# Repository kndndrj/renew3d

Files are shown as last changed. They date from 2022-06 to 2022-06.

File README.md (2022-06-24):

# Renew3D
A simple, cheap and (hopefully) reliable 3D printer.

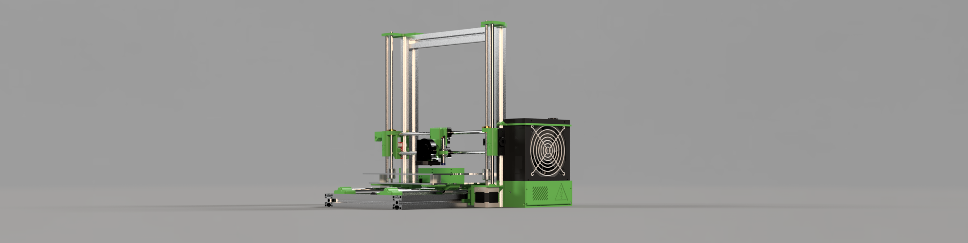
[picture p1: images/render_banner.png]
render


[More images here.](images/)

###### What kind of name is this?
I built my first 3D printer a couple of years ago, but there was no assembly,
only parts from thingiverse, etc. Then I had an idea to make a new printer with
extra features, but the project became *waaay* to complicated (check it
[here](https://github.com/kndndrj/complicator-3000)). So this printer here, is
a "renewed" version of those two (quite bad, I know).

## Getting Started
The files for this printer are available in `.f3d`, `.step` and `.stl` formats.
If you want to assemble the printer, I suggest that you check
[`assembly.f3z`](cad/assembly.f3z) (alternatively `assembly.step`) first, and
check what materials to buy and what parts to print. Then look into the
[`printed_parts`](cad/printed_parts) directory and browse files in different
formats. If you have a sensor, board, hotend, etc. check the `extras`
directory.

## Firmware Uploading (Linux)
You can use any firmware you like, here is just my example config using Marlin
2.0.x for Ramps board with mega 2560.

1. Download Marlin Firmware [here](https://github.com/MarlinFirmware/Marlin).
2. Install platformio (example on Arch Linux):
	```sh
	$ paru -S platformio
	```
3. Go to the downloaded firmware directory and replace `Marlin/Configuration.h`
   and `Marlin/Configuration_adv.h` with files from [`firmware`](firmware) in
   this repository.
4. Plug in the printer and run:
	```sh
	$ platformio run --target upload -e mega2560
	```

#### Note on cheap Chinese boards
Try these steps (stop when you get it to work):
- Install `i2c-ch341-dkms` from AUR.
- Disable udev rules:
	```
	/usr/lib/udev/rules.d/90-brltty-device.rules
	/usr/lib/udev/rules.d/90-brltty-uinput.rules
	```
- Specify `upload_port = /dev/ttyUSB0` in `ini/avr.ini`

## Development

#### Specific Components
If you are creating a new specific part (like SKR 1.3), put it in the `extras`
directory. If it's made of multiple bodies, export the whole file as `.f3d` and
`.step`. Then export separate bodies (only printable parts) as `.stl`.

#### Main Assembly
For main assembly, use only the `assembly.f3z` when developing. then export the
modified printable parts in all formats and put them in `main_assembly`
directory.

## Credits

#### Standard Parts 3D Models:

**NOTE:** I'm not the owner of any of the following "standard" parts.

- [atx_power_supply](https://grabcad.com/library/atx-power-supply-1)
- [cooling_fan_4010](https://grabcad.com/library/40mm-dc-fan-1)
- [cooling_fan_radial_5015](https://grabcad.com/library/radial-cooling-5015-fan-50mm-dc12v-1/details?folder_id=2074285)
- [e3d_v6_hotend](https://grabcad.com/library/e3d-v6-hotend-1-75mm-bowden-1)
- [endstop_switch](https://grabcad.com/library/mechanical-endstop-module-1)
- [flex_coupler_5x8]()https://grabcad.com/library/flex-coupler-5mm-8mm-1
- [GT2_20T_motor](https://grabcad.com/library/timing-pulley-gt2-20-teeth-5mm-bore-2/details?folder_id=2369004)
- [GT2_20T_idler](https://grabcad.com/library/tension-pulley-gt2-20t-b5-1)
- [induction_sensor_m12](https://grabcad.com/library/lj12a3-4-z_bx-inductive-sensor-m12-1)
- [lead_screw_nut_t8](https://grabcad.com/library/tr8x8-4-8mm-4-start-lead-screw-nut-1)
- [lead_screw_t8_340](https://grabcad.com/library/tr8x8-4-8mm-4-start-lead-screw-1)
- [linear_bearing_LM8UU](https://grabcad.com/library/lm8uu-11)
- [nema_17_motor](https://grabcad.com/library/step-motor-nema-17-1)
- [ramps_14_arduino_mega_2560](https://grabcad.com/library/arduino-mega-ramps-1-4-1)
- [ramps_lcd_adapter](https://grabcad.com/library/smart-adapter-conector-lcd-ramps-1-4-1)
- [SSR_40_DA](https://grabcad.com/library/ssr-40-da-1)

#### Printed Parts:

- [part_cooling_fan_duct](https://www.thingiverse.com/thing:3063554) - changed only text
- [x_idler & x_motor_holder](https://www.thingiverse.com/thing:1103976) - fork
- [x_carriage & hotend_holder](https://www.thingiverse.com/thing:2023947) - fork
- [y_endstop_holder](https://www.thingiverse.com/thing:919432/files) - inspiration

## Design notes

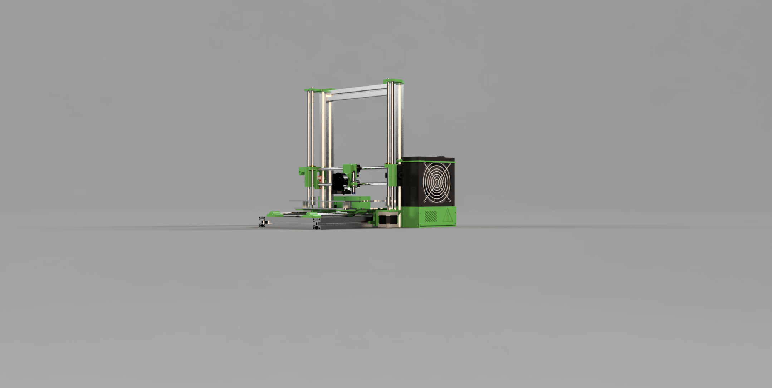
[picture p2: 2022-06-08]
images/render.png

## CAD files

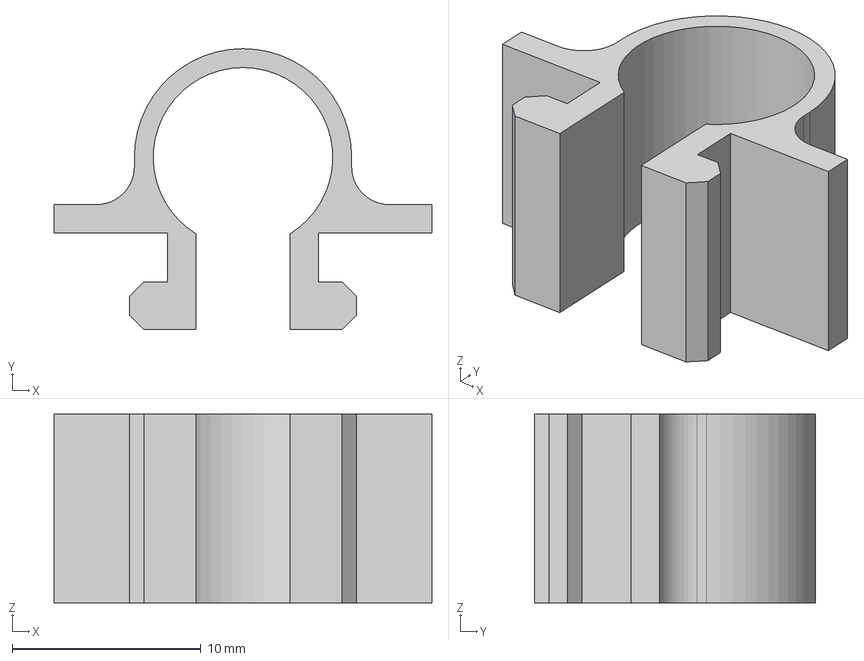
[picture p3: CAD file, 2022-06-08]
cad/printed_parts/extras/step/cable_clip.step
20.0 x 14.8 x 10.0 mm

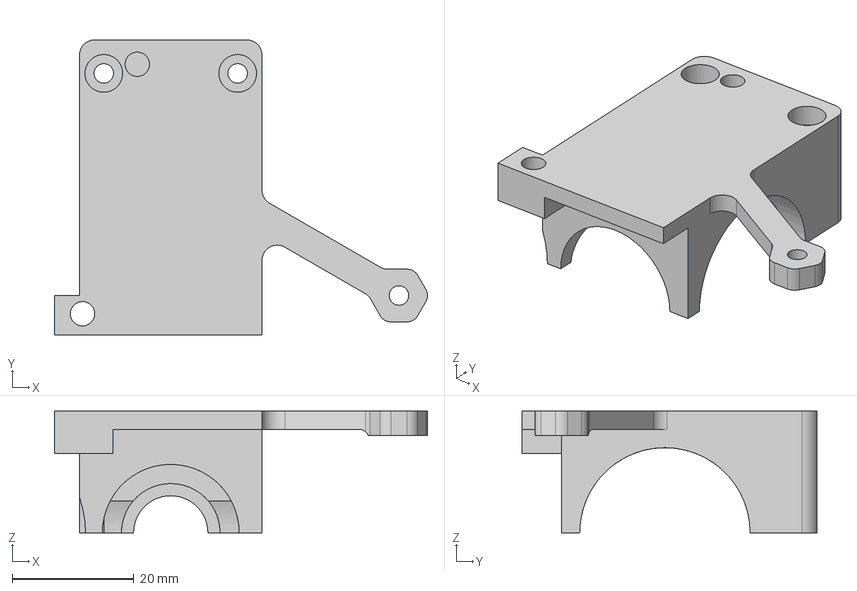
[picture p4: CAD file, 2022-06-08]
cad/printed_parts/main_assembly/step/hotend_holder_cover.step
61.3 x 48.5 x 20.0 mm

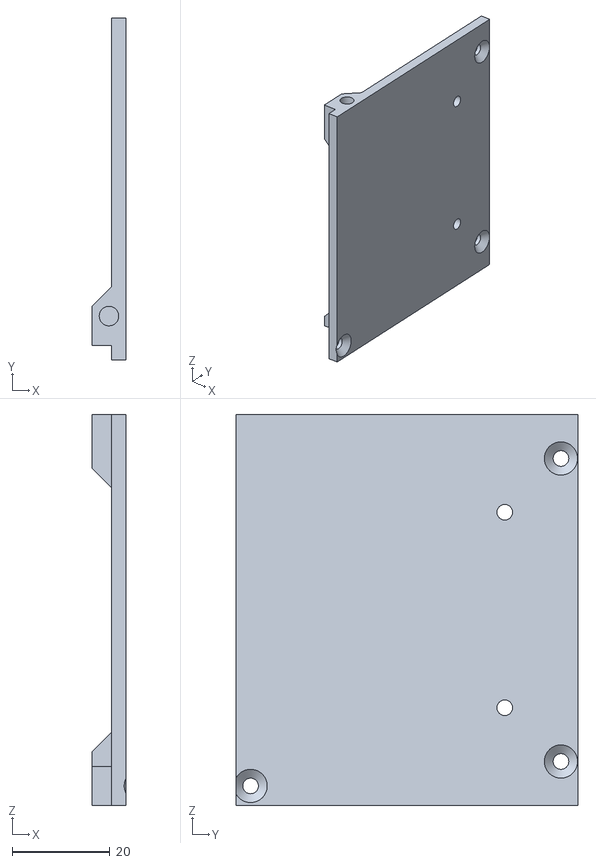
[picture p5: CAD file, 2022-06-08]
cad/printed_parts/main_assembly/stl/ramps_enclosure_right.stl
7.00 x 70.0 x 80.0

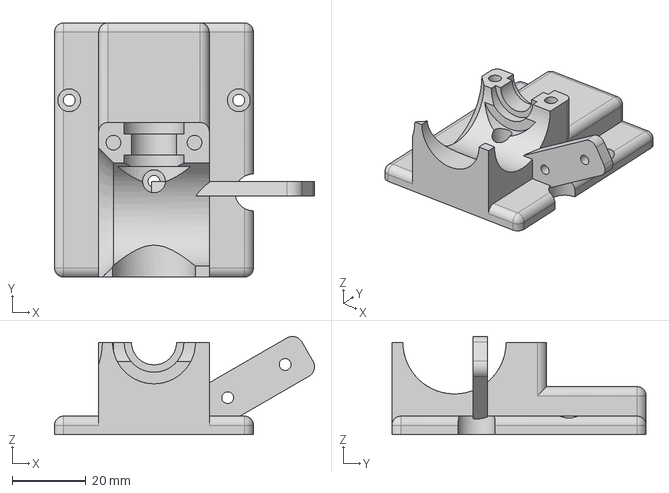
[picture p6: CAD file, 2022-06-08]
cad/printed_parts/extras/step/hotend_holder_back_bl_touch.step
70.6 x 69.0 x 26.6 mm

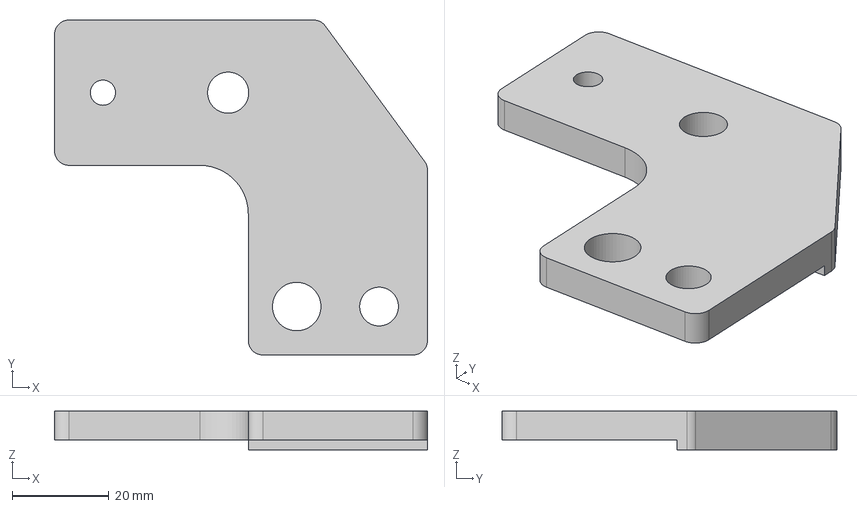
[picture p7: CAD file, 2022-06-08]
cad/printed_parts/main_assembly/step/z_guide_holder_right.step
77.0 x 69.2 x 8.00 mm

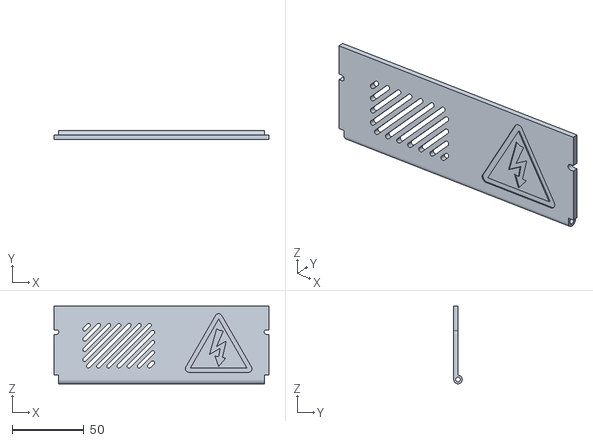
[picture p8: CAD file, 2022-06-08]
cad/printed_parts/main_assembly/stl/ssr_enclosure_front.stl
149.5 x 6.00 x 54.0

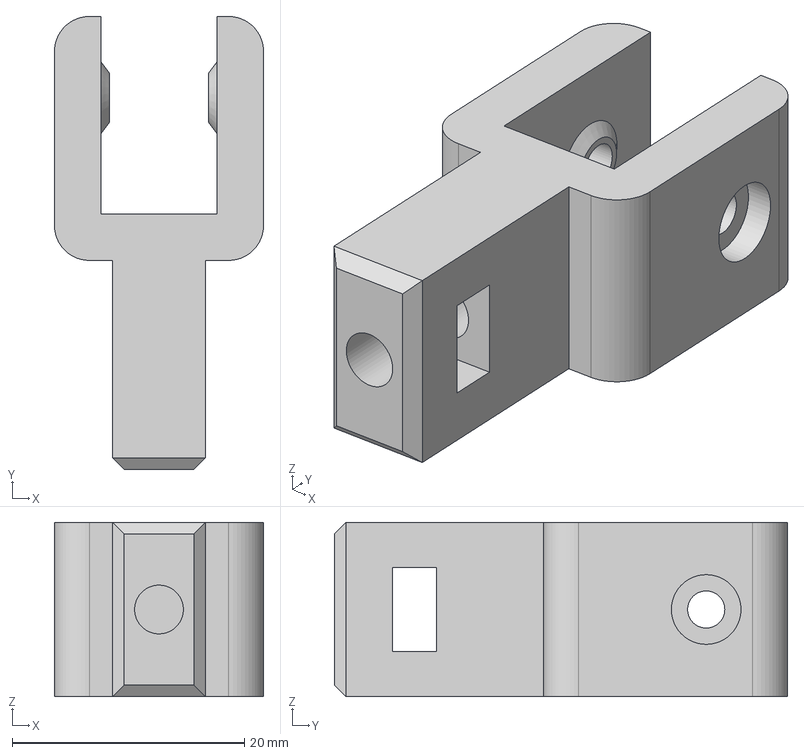
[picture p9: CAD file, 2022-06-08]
cad/printed_parts/main_assembly/step/tension_arm.step
18.0 x 39.0 x 15.0 mm

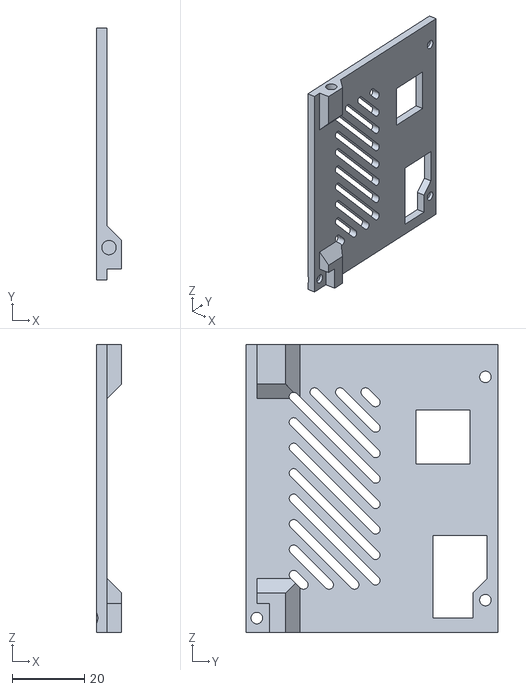
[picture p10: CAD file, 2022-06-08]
cad/printed_parts/main_assembly/stl/ramps_enclosure_left.stl
7.00 x 70.0 x 80.0

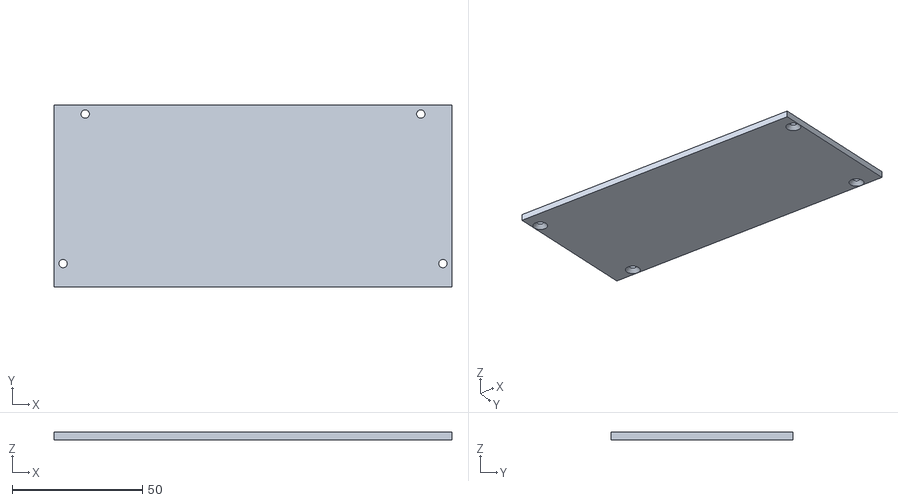
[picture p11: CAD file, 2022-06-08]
cad/printed_parts/main_assembly/stl/ramps_enclosure_bottom.stl
153.0 x 70.0 x 3.00

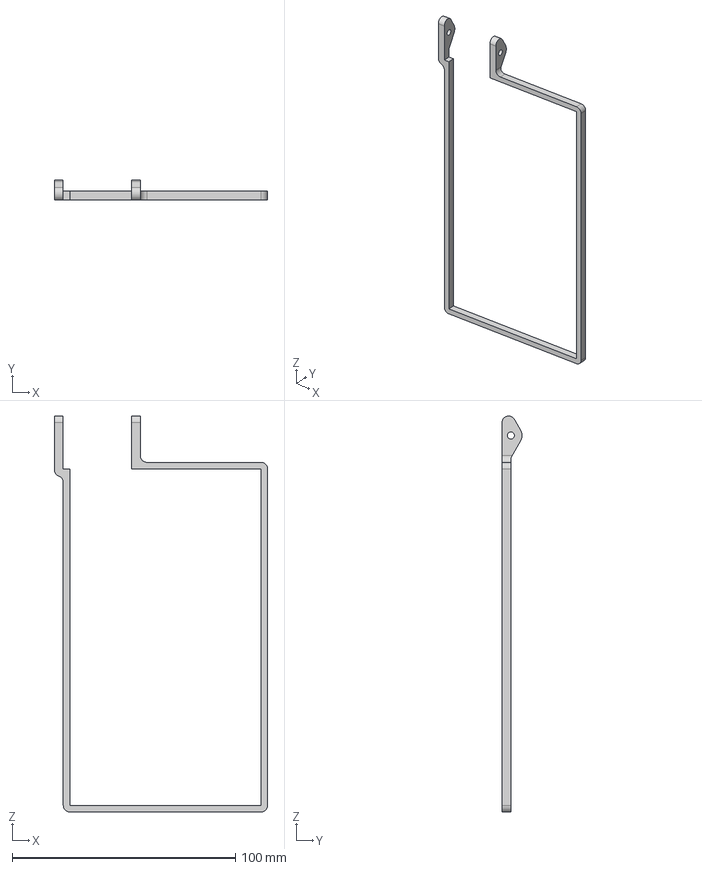
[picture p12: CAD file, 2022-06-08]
cad/printed_parts/main_assembly/step/psu_support.step
95.5 x 8.99 x 177.2 mm

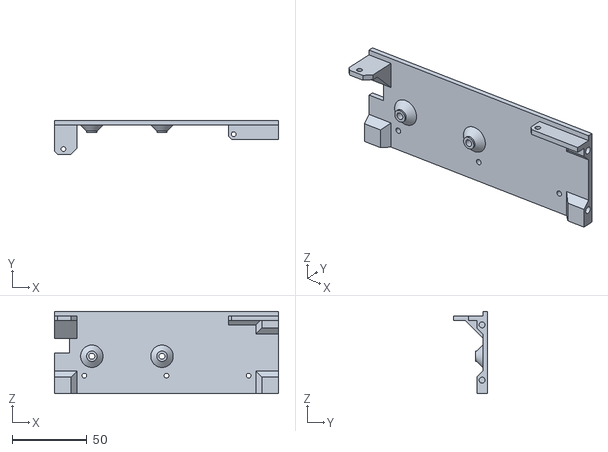
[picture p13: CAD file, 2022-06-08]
cad/printed_parts/main_assembly/stl/ssr_enclosure_back.stl
150.0 x 22.5 x 55.0

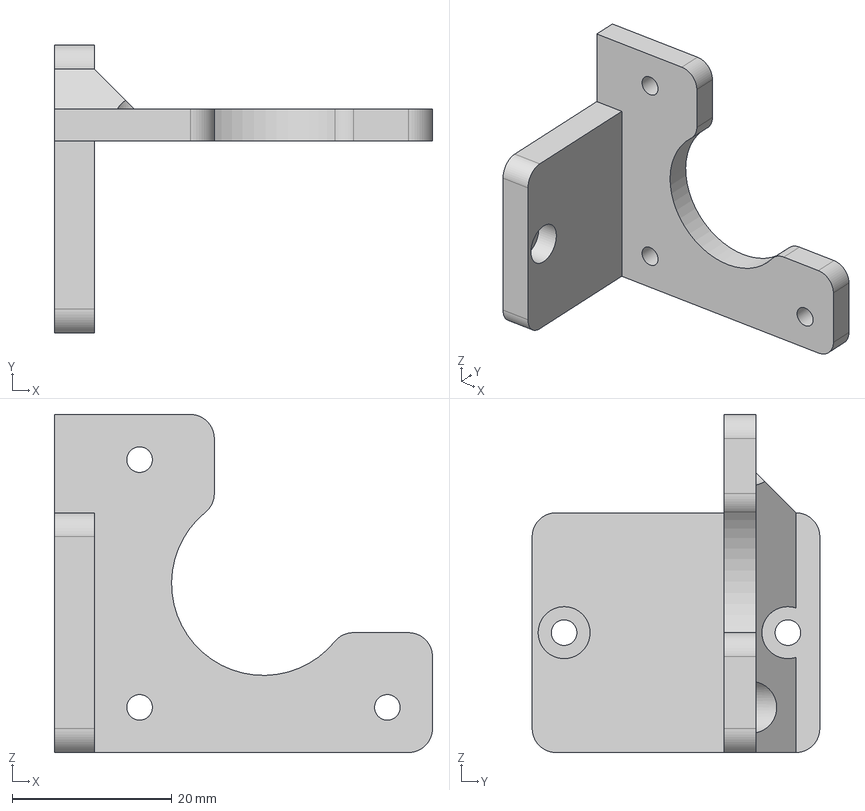
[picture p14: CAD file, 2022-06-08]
cad/printed_parts/main_assembly/step/y_motor_holder.step
47.3 x 36.0 x 42.3 mm

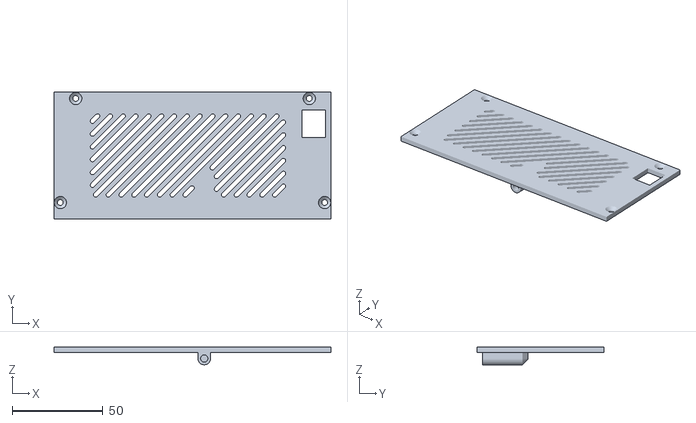
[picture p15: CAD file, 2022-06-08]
cad/printed_parts/main_assembly/stl/ramps_enclosure_top.stl
153.0 x 70.0 x 9.74

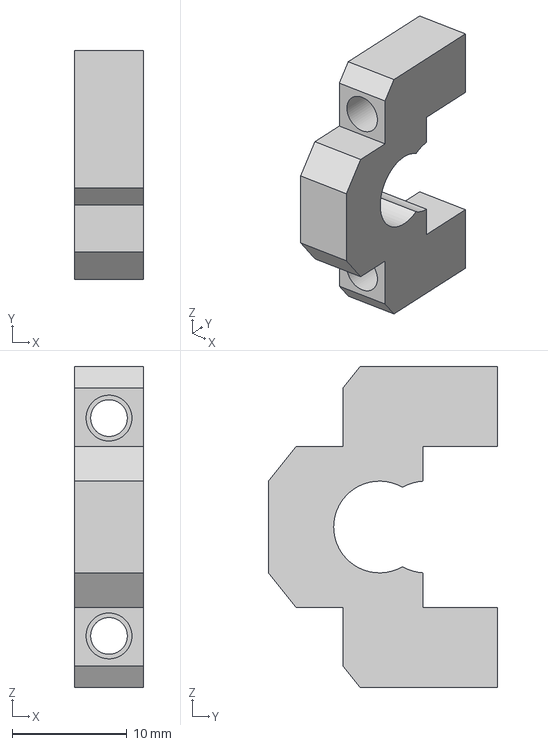
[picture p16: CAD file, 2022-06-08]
cad/printed_parts/main_assembly/step/y_endstop_holder.step
6.00 x 20.0 x 28.0 mm

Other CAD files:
cad/printed_parts/main_assembly/stl/ssr_enclosure_left.stl
cad/printed_parts/main_assembly/step/x_tensioner.step
cad/printed_parts/main_assembly/stl/ssr_enclosure_bottom.stl
cad/printed_parts/main_assembly/step/x_idler.step
cad/printed_parts/extras/f3d/cable_clip.f3d
cad/printed_parts/extras/f3d/hotend_holder_bl_touch.f3d
cad/printed_parts/extras/stl/cable_clip.stl
cad/printed_parts/extras/stl/hotend_holder_back_bl_touch.stl
cad/printed_parts/main_assembly/f3d/hotend_holder_induction_probe_12.f3d
cad/printed_parts/main_assembly/f3d/part_cooling_fan_duct.f3d
cad/printed_parts/main_assembly/f3d/psu_support.f3d
cad/printed_parts/main_assembly/f3d/screw_wheel_20_m4.f3d
cad/printed_parts/main_assembly/f3d/screw_wheel_27_m4.f3d
cad/printed_parts/main_assembly/f3d/screw_wheel_60_m3.f3d
cad/printed_parts/main_assembly/f3d/tension_arm.f3d
cad/printed_parts/main_assembly/f3d/x_carriage.f3d
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

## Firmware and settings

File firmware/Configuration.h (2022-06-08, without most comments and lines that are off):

#pragma once
#define CONFIGURATION_H_VERSION 02000903
#define STRING_CONFIG_H_AUTHOR "(Andrej Kenda, Renew3D config)" // Who made the changes.
#define SHOW_BOOTSCREEN
  #define MOTHERBOARD BOARD_RAMPS_14_EFB
#define SERIAL_PORT 0
#define BAUDRATE 250000
#define CUSTOM_MACHINE_NAME "Renew3D"
#if LINEAR_AXES >= 4
  #define AXIS4_NAME 'A' // :['A', 'B', 'C', 'U', 'V', 'W']
#endif
#if LINEAR_AXES >= 5
  #define AXIS5_NAME 'B' // :['A', 'B', 'C', 'U', 'V', 'W']
#endif
#if LINEAR_AXES >= 6
  #define AXIS6_NAME 'C' // :['A', 'B', 'C', 'U', 'V', 'W']
#endif
#define EXTRUDERS 1
#define DEFAULT_NOMINAL_FILAMENT_DIA 1.75
#define TEMP_SENSOR_0 1
#define TEMP_SENSOR_1 0
#define TEMP_SENSOR_2 0
#define TEMP_SENSOR_3 0
#define TEMP_SENSOR_4 0
#define TEMP_SENSOR_5 0
#define TEMP_SENSOR_6 0
#define TEMP_SENSOR_7 0
#define TEMP_SENSOR_BED 75
#define TEMP_SENSOR_PROBE 0
#define TEMP_SENSOR_CHAMBER 0
#define TEMP_SENSOR_COOLER 0
#define TEMP_SENSOR_BOARD 0
#define TEMP_SENSOR_REDUNDANT 0
#define DUMMY_THERMISTOR_998_VALUE  25
#define DUMMY_THERMISTOR_999_VALUE 100
#define TEMP_RESIDENCY_TIME         10  // (seconds) Time to wait for hotend to "settle" in M109
#define TEMP_WINDOW                  1  // (°C) Temperature proximity for the "temperature reached" timer
#define TEMP_HYSTERESIS              3  // (°C) Temperature proximity considered "close enough" to the target
#define TEMP_BED_RESIDENCY_TIME     10  // (seconds) Time to wait for bed to "settle" in M190
#define TEMP_BED_WINDOW              1  // (°C) Temperature proximity for the "temperature reached" timer
#define TEMP_BED_HYSTERESIS          3  // (°C) Temperature proximity considered "close enough" to the target
#define TEMP_CHAMBER_RESIDENCY_TIME 10  // (seconds) Time to wait for chamber to "settle" in M191
#define TEMP_CHAMBER_WINDOW          1  // (°C) Temperature proximity for the "temperature reached" timer
#define TEMP_CHAMBER_HYSTERESIS      3  // (°C) Temperature proximity considered "close enough" to the target
#if TEMP_SENSOR_REDUNDANT
  #define TEMP_SENSOR_REDUNDANT_SOURCE    E1  // The sensor that will provide the redundant reading.
  #define TEMP_SENSOR_REDUNDANT_TARGET    E0  // The sensor that we are providing a redundant reading for.
  #define TEMP_SENSOR_REDUNDANT_MAX_DIFF  10  // (°C) Temperature difference that will trigger a print abort.
#endif
#define HEATER_0_MINTEMP   10
#define HEATER_1_MINTEMP   5
#define HEATER_2_MINTEMP   5
#define HEATER_3_MINTEMP   5
#define HEATER_4_MINTEMP   5
#define HEATER_5_MINTEMP   5
#define HEATER_6_MINTEMP   5
#define HEATER_7_MINTEMP   5
#define BED_MINTEMP        10
#define CHAMBER_MINTEMP    5
#define HEATER_0_MAXTEMP 275
#define HEATER_1_MAXTEMP 275
#define HEATER_2_MAXTEMP 275
#define HEATER_3_MAXTEMP 275
#define HEATER_4_MAXTEMP 275
#define HEATER_5_MAXTEMP 275
#define HEATER_6_MAXTEMP 275
#define HEATER_7_MAXTEMP 275
#define BED_MAXTEMP      90
#define CHAMBER_MAXTEMP  60
#define HOTEND_OVERSHOOT 15   // (°C) Forbid temperatures over MAXTEMP - OVERSHOOT
#define BED_OVERSHOOT    10   // (°C) Forbid temperatures over MAXTEMP - OVERSHOOT
#define COOLER_OVERSHOOT  2   // (°C) Forbid temperatures closer than OVERSHOOT
#define PIDTEMP
#define BANG_MAX 255     // Limits current to nozzle while in bang-bang mode; 255=full current
#define PID_MAX BANG_MAX // Limits current to nozzle while PID is active (see PID_FUNCTIONAL_RANGE below); 255=full current
#define PID_K1 0.95      // Smoothing factor within any PID loop
    #define DEFAULT_Kp 12.54
    #define DEFAULT_Ki 0.59
    #define DEFAULT_Kd 66.76
#define PIDTEMPBED
#define MAX_BED_POWER 255 // limits duty cycle to bed; 255=full current
  #define DEFAULT_bedKp 29.51
  #define DEFAULT_bedKi 5.00
  #define DEFAULT_bedKd 116.02
#define MAX_CHAMBER_POWER 255 // limits duty cycle to chamber heater; 255=full current
  #define PID_FUNCTIONAL_RANGE 10 // If the temperature difference between the target temperature and the actual temperature
#define PREVENT_COLD_EXTRUSION
#define EXTRUDE_MINTEMP 170
#define PREVENT_LENGTHY_EXTRUDE
#define EXTRUDE_MAXLENGTH 200
#define THERMAL_PROTECTION_HOTENDS // Enable thermal protection for all extruders
#define THERMAL_PROTECTION_BED     // Enable thermal protection for the heated bed
#define THERMAL_PROTECTION_CHAMBER // Enable thermal protection for the heated chamber
#define THERMAL_PROTECTION_COOLER  // Enable thermal protection for the laser cooling
#define USE_XMIN_PLUG
#define USE_YMIN_PLUG
#define USE_ZMIN_PLUG
#define ENDSTOPPULLUPS
#define X_MIN_ENDSTOP_INVERTING true  // Set to true to invert the logic of the endstop.
#define Y_MIN_ENDSTOP_INVERTING true  // Set to true to invert the logic of the endstop.
#define Z_MIN_ENDSTOP_INVERTING false // Set to true to invert the logic of the endstop.
#define I_MIN_ENDSTOP_INVERTING false // Set to true to invert the logic of the endstop.
#define J_MIN_ENDSTOP_INVERTING false // Set to true to invert the logic of the endstop.
#define K_MIN_ENDSTOP_INVERTING false // Set to true to invert the logic of the endstop.
#define X_MAX_ENDSTOP_INVERTING false // Set to true to invert the logic of the endstop.
#define Y_MAX_ENDSTOP_INVERTING false // Set to true to invert the logic of the endstop.
#define Z_MAX_ENDSTOP_INVERTING false // Set to true to invert the logic of the endstop.
#define I_MAX_ENDSTOP_INVERTING false // Set to true to invert the logic of the endstop.
#define J_MAX_ENDSTOP_INVERTING false // Set to true to invert the logic of the endstop.
#define K_MAX_ENDSTOP_INVERTING false // Set to true to invert the logic of the endstop.
#define Z_MIN_PROBE_ENDSTOP_INVERTING false // Set to true to invert the logic of the probe.
#define X_DRIVER_TYPE  DRV8825
#define Y_DRIVER_TYPE  DRV8825
#define Z_DRIVER_TYPE  DRV8825
#define E0_DRIVER_TYPE DRV8825
#define DEFAULT_AXIS_STEPS_PER_UNIT   { 160, 160, 800, 192 }
#define DEFAULT_MAX_FEEDRATE          { 100, 100, 5, 25 }
#define DEFAULT_MAX_ACCELERATION      { 900, 900, 100, 5000 }
#define DEFAULT_ACCELERATION          1000    // X, Y, Z and E acceleration for printing moves
#define DEFAULT_RETRACT_ACCELERATION  1000    // E acceleration for retracts
#define DEFAULT_TRAVEL_ACCELERATION   1000    // X, Y, Z acceleration for travel (non printing) moves
#define CLASSIC_JERK
  #define DEFAULT_XJERK 10.0
  #define DEFAULT_YJERK 10.0
  #define DEFAULT_ZJERK  0.4
#define DEFAULT_EJERK    5.0  // May be used by Linear Advance
#define Z_MIN_PROBE_USES_Z_MIN_ENDSTOP_PIN
#define USE_PROBE_FOR_Z_HOMING
#define BLTOUCH
#define NOZZLE_TO_PROBE_OFFSET { 23, 3, -1.5 }
#define PROBING_MARGIN 10
#define XY_PROBE_FEEDRATE (133*60)
#define Z_PROBE_FEEDRATE_FAST (4*60)
#define Z_PROBE_FEEDRATE_SLOW (Z_PROBE_FEEDRATE_FAST / 2)
#define Z_CLEARANCE_DEPLOY_PROBE    4 // Z Clearance for Deploy/Stow
#define Z_CLEARANCE_BETWEEN_PROBES  4 // Z Clearance between probe points
#define Z_CLEARANCE_MULTI_PROBE     4 // Z Clearance between multiple probes
#define Z_PROBE_LOW_POINT          -2 // Farthest distance below the trigger-point to go before stopping
#define Z_PROBE_OFFSET_RANGE_MIN -20
#define Z_PROBE_OFFSET_RANGE_MAX 20
#define X_ENABLE_ON 0
#define Y_ENABLE_ON 0
#define Z_ENABLE_ON 0
#define E_ENABLE_ON 0 // For all extruders
#define DISABLE_X false
#define DISABLE_Y false
#define DISABLE_Z false
#define DISABLE_E false             // Disable the extruder when not stepping
#define DISABLE_INACTIVE_EXTRUDER   // Keep only the active extruder enabled
#define INVERT_X_DIR false
#define INVERT_Y_DIR true
#define INVERT_Z_DIR false
#define INVERT_E0_DIR true
#define INVERT_E1_DIR false
#define INVERT_E2_DIR false
#define INVERT_E3_DIR false
#define INVERT_E4_DIR false
#define INVERT_E5_DIR false
#define INVERT_E6_DIR false
#define INVERT_E7_DIR false
#define X_HOME_DIR -1
#define Y_HOME_DIR -1
#define Z_HOME_DIR -1
#define X_BED_SIZE 225
#define Y_BED_SIZE 225
#define X_MIN_POS 0
#define Y_MIN_POS 0
#define Z_MIN_POS 0
#define X_MAX_POS X_BED_SIZE
#define Y_MAX_POS Y_BED_SIZE
#define Z_MAX_POS 200
#define MIN_SOFTWARE_ENDSTOPS
  #define MIN_SOFTWARE_ENDSTOP_X
  #define MIN_SOFTWARE_ENDSTOP_Y
  #define MIN_SOFTWARE_ENDSTOP_Z
  #define MIN_SOFTWARE_ENDSTOP_I
  #define MIN_SOFTWARE_ENDSTOP_J
  #define MIN_SOFTWARE_ENDSTOP_K
#define MAX_SOFTWARE_ENDSTOPS
  #define MAX_SOFTWARE_ENDSTOP_X
  #define MAX_SOFTWARE_ENDSTOP_Y
  #define MAX_SOFTWARE_ENDSTOP_Z
  #define MAX_SOFTWARE_ENDSTOP_I
  #define MAX_SOFTWARE_ENDSTOP_J
  #define MAX_SOFTWARE_ENDSTOP_K
#define AUTO_BED_LEVELING_BILINEAR
  #define ENABLE_LEVELING_FADE_HEIGHT
    #define DEFAULT_LEVELING_FADE_HEIGHT 10.0 // (mm) Default fade height.
  #define SEGMENT_LEVELED_MOVES
  #define LEVELED_SEGMENT_LENGTH 5.0 // (mm) Length of all segments (except the last one)
  #define GRID_MAX_POINTS_X 3
  #define GRID_MAX_POINTS_Y GRID_MAX_POINTS_X
#define Z_SAFE_HOMING
  #define Z_SAFE_HOMING_X_POINT X_CENTER  // X point for Z homing
  #define Z_SAFE_HOMING_Y_POINT Y_CENTER  // Y point for Z homing
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

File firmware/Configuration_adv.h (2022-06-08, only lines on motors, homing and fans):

#define E0_AUTO_FAN_PIN -1
#define E1_AUTO_FAN_PIN -1
#define E2_AUTO_FAN_PIN -1
#define E3_AUTO_FAN_PIN -1
#define E4_AUTO_FAN_PIN -1
#define E5_AUTO_FAN_PIN -1
#define E6_AUTO_FAN_PIN -1
#define E7_AUTO_FAN_PIN -1
#define CHAMBER_AUTO_FAN_PIN -1
#define COOLER_AUTO_FAN_PIN -1
#define HOMING_BUMP_MM      { 5, 5, 2 }       // (mm) Backoff from endstops after first bump
#define HOMING_BUMP_DIVISOR { 2, 2, 4 }       // Re-Bump Speed Divisor (Divides the Homing Feedrate)
#define MICROSTEP_MODES { 16, 16, 16, 16, 16, 16 } // [1,2,4,8,16]

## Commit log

2022-06-08 added 3D models and a README
    [cable_clip.f3d, cable_clip.step, cable_clip.stl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]
2022-06-08 added marlin firmware example configs
    [Configuration.h, Configuration_adv.h]

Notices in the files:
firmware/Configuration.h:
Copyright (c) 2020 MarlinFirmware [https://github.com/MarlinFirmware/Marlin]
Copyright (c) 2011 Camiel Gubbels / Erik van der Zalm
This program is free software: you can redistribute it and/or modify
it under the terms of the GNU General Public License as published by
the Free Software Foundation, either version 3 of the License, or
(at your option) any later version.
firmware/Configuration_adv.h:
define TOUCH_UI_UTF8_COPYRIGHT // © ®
